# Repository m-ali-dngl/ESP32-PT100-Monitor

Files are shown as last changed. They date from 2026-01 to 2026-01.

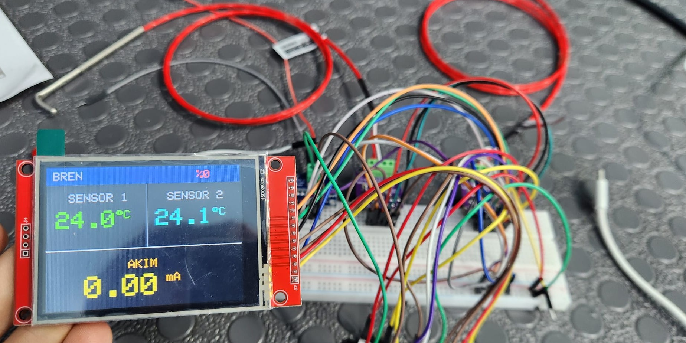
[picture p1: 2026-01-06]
Docs/Görsel.jpeg

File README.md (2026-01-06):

#  ESP32 Industrial Dual-Channel PT100 & Power Monitor

##  Overview

This project is designed for field engineers and technicians who need to monitor temperature and power parameters simultaneously. It utilizes the **ESP32** microcontroller to process data from two **PT100 RTD sensors** (via MAX31865) and an **INA219** current sensor. The data is displayed on a crisp **2.8" ILI9341 TFT screen** with a custom graphical user interface.

##  Key Features

* **Dual Temperature Monitoring:** High-precision reading from 2x PT100 sensors using MAX31865 (SPI).
* **Power Analysis:** Real-time current monitoring (mA) for external loads via INA219 (I2C).
* **Battery Management:**
    * Integrated 3.7V Li-Po battery support.
    * On-board charging (TP4056) and Boost Converter (MT3608) for stable 5V system power.
    * **Smart Battery Level:** ADC-based voltage monitoring with a voltage divider (100kΩ/100kΩ) and software calibration.
* **User Interface:**
    * Custom boot logo (Splash Screen).
    * Color-coded alerts (Green/Yellow/Red) for battery levels and sensor status.
* **PCB Design:** Schematic and PCB layout created in **Altium Designer**.

##  Project Structure

```text
├── Software/          # Arduino source codes (.ino) and header files
├── Hardware/          # Altium Designer Project files
└── Docs/              # Documentation, schematics PDF, and images

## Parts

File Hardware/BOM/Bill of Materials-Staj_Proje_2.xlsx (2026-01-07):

Comment | Description | Designator | Footprint | LibRef | Quantity
RES_100K | RES_100K | R1, R2 | RES | RES_100K | 2
SCREEN | SCREEN | SCR1 | LCD | SCREEN | 1
SWİTCH | SWİTCH | SW1 | SWİTCH | SWİTCH | 1
MAX 31865 | MAX 31865 | U1, U4 | MAX31865 | MAX_31865 | 2
TP4056 | TP4056 | U2 | TP4056 | TP4056 | 1
MT3608 | MT3608 | U3 | MT3608 | MT3608 | 1
INA219 | INA219 | U5 | INA219 | INA_219 | 1
ESP32 | ESP32 | U6 | ESP32 | ESP32 | 1

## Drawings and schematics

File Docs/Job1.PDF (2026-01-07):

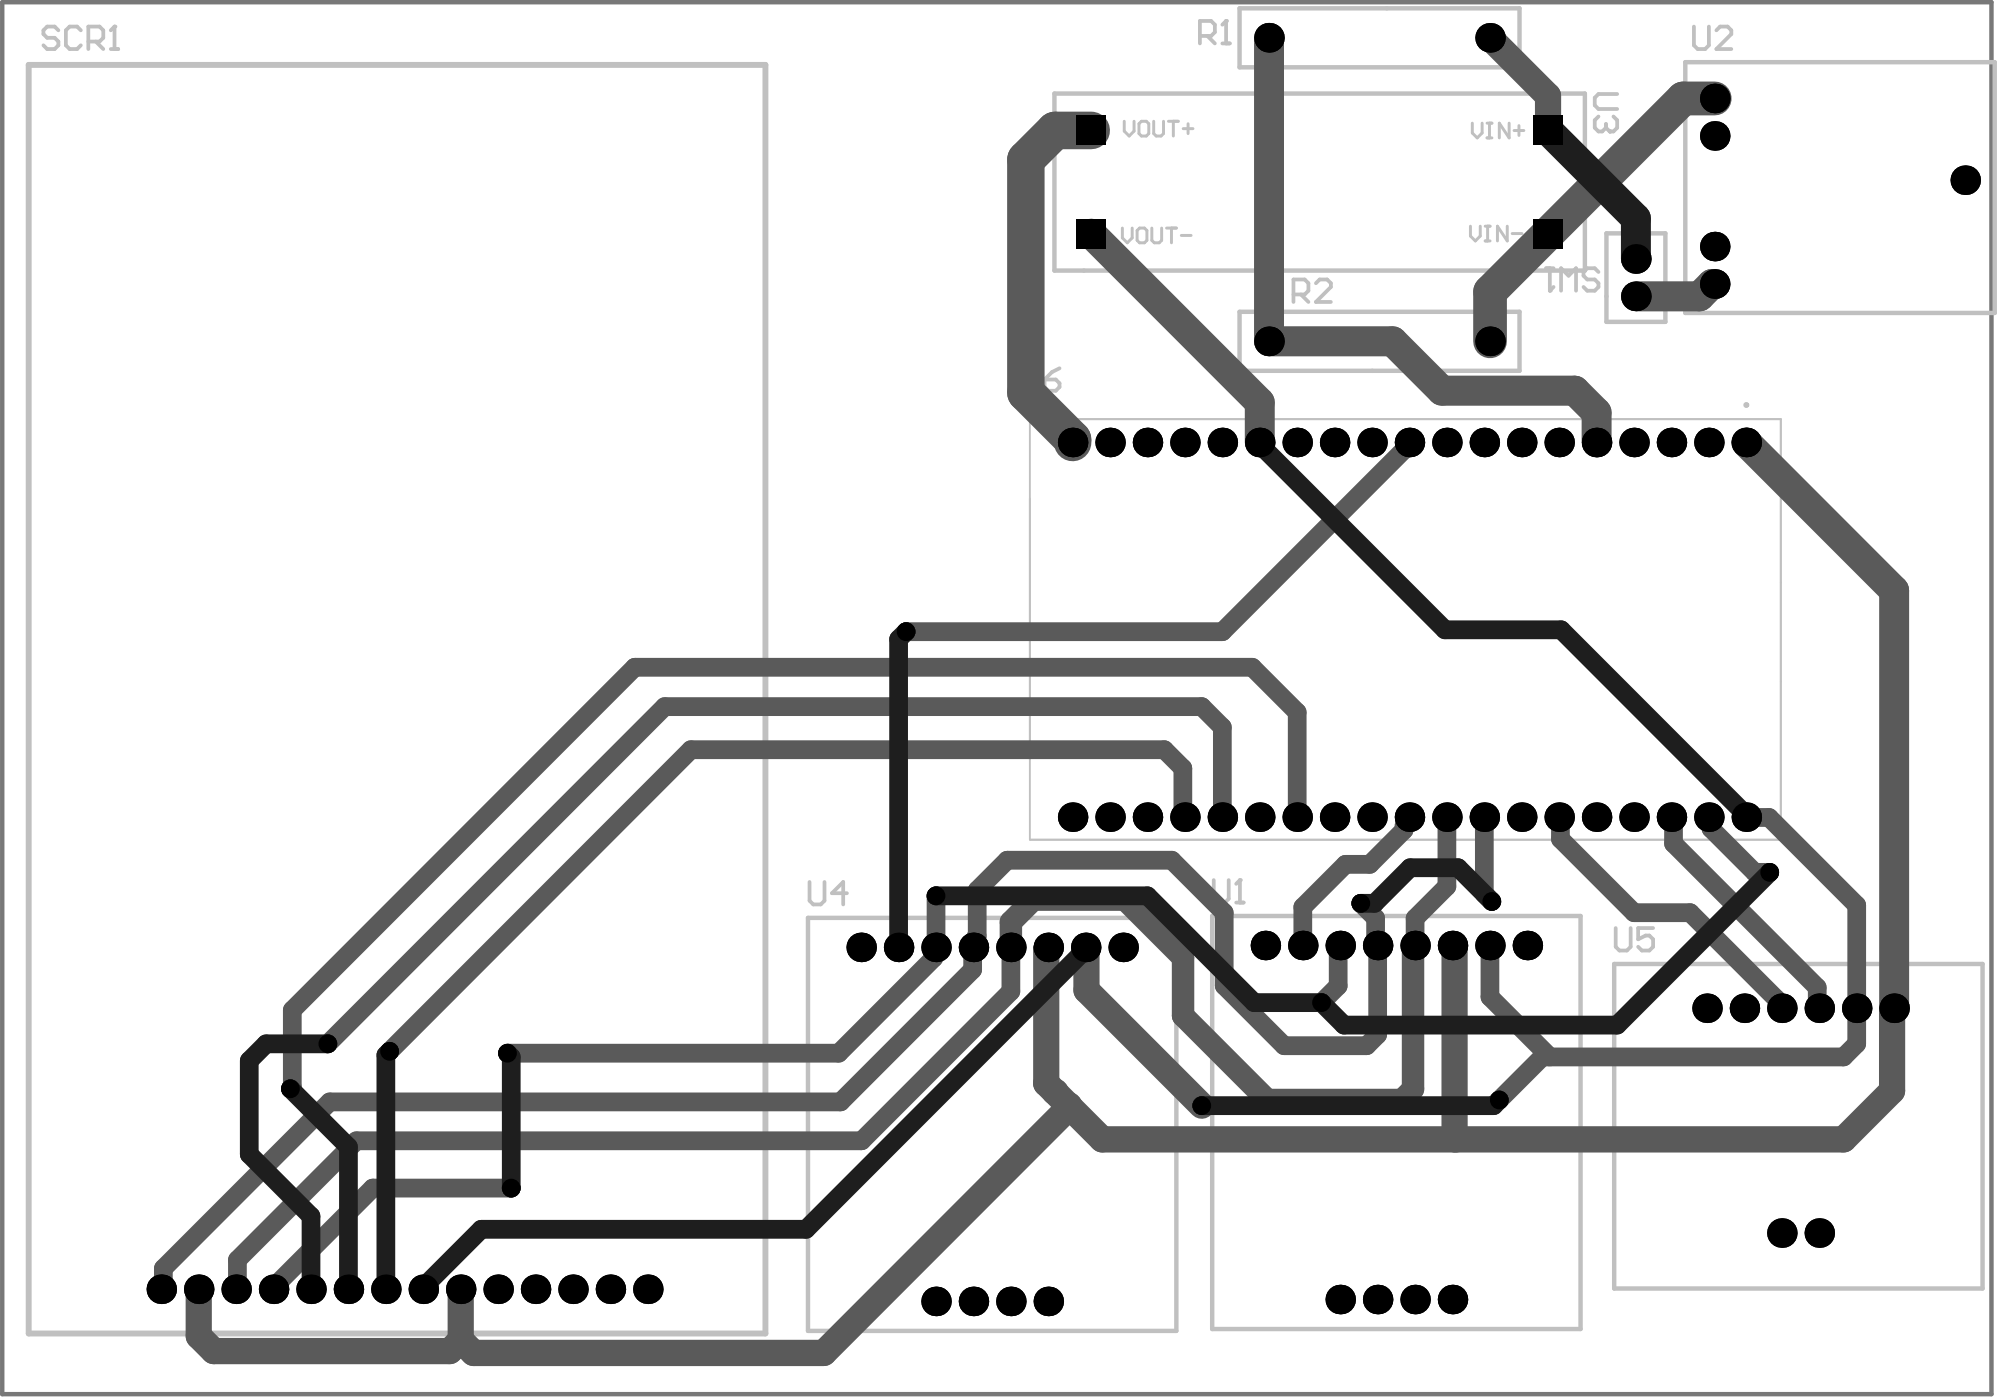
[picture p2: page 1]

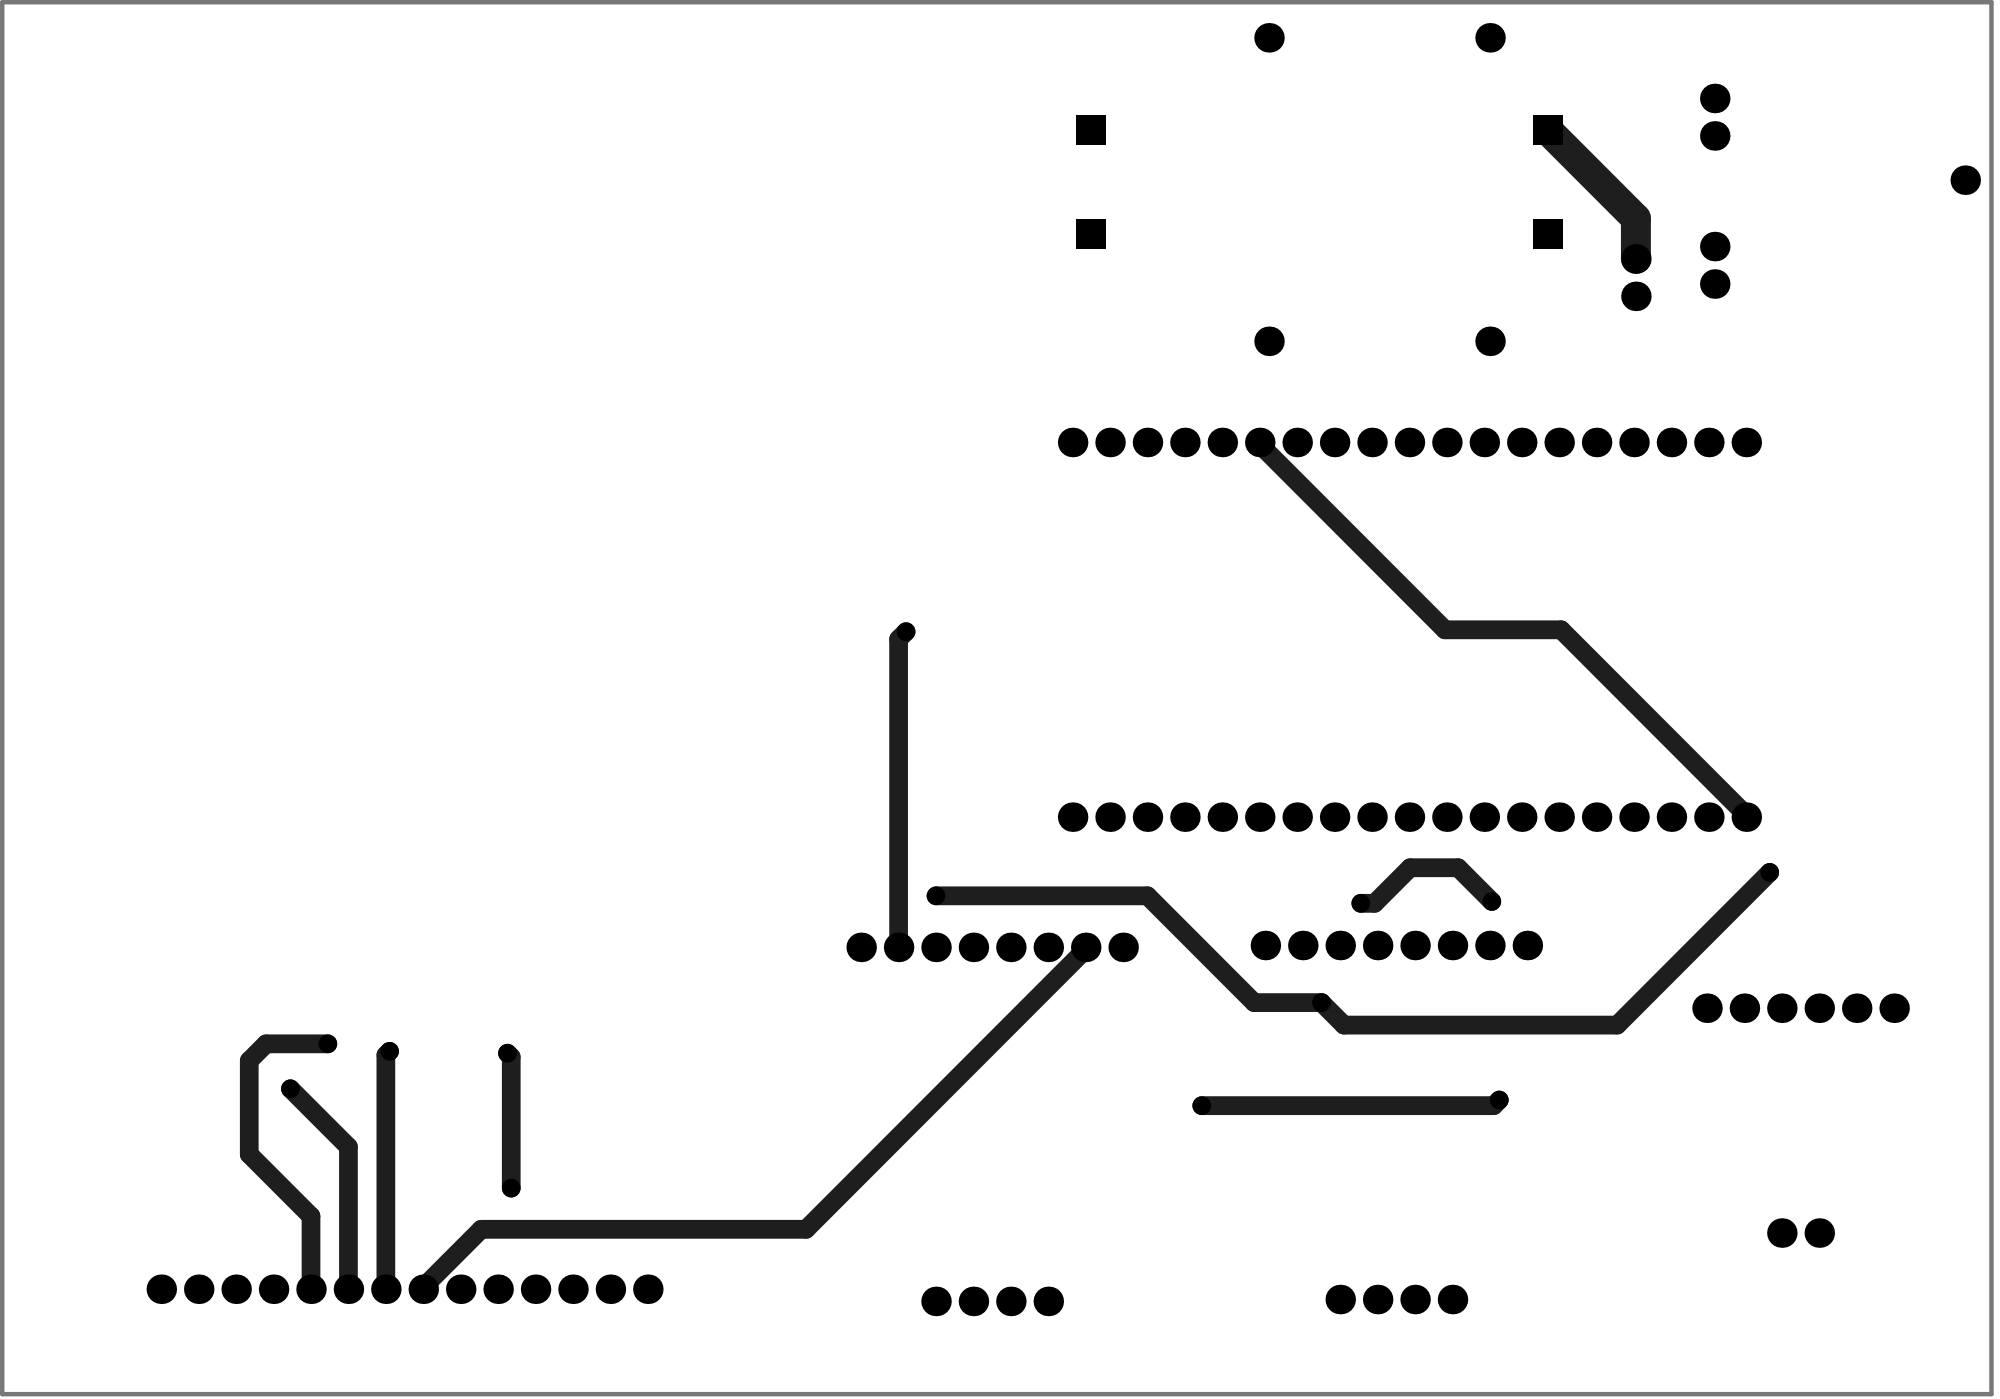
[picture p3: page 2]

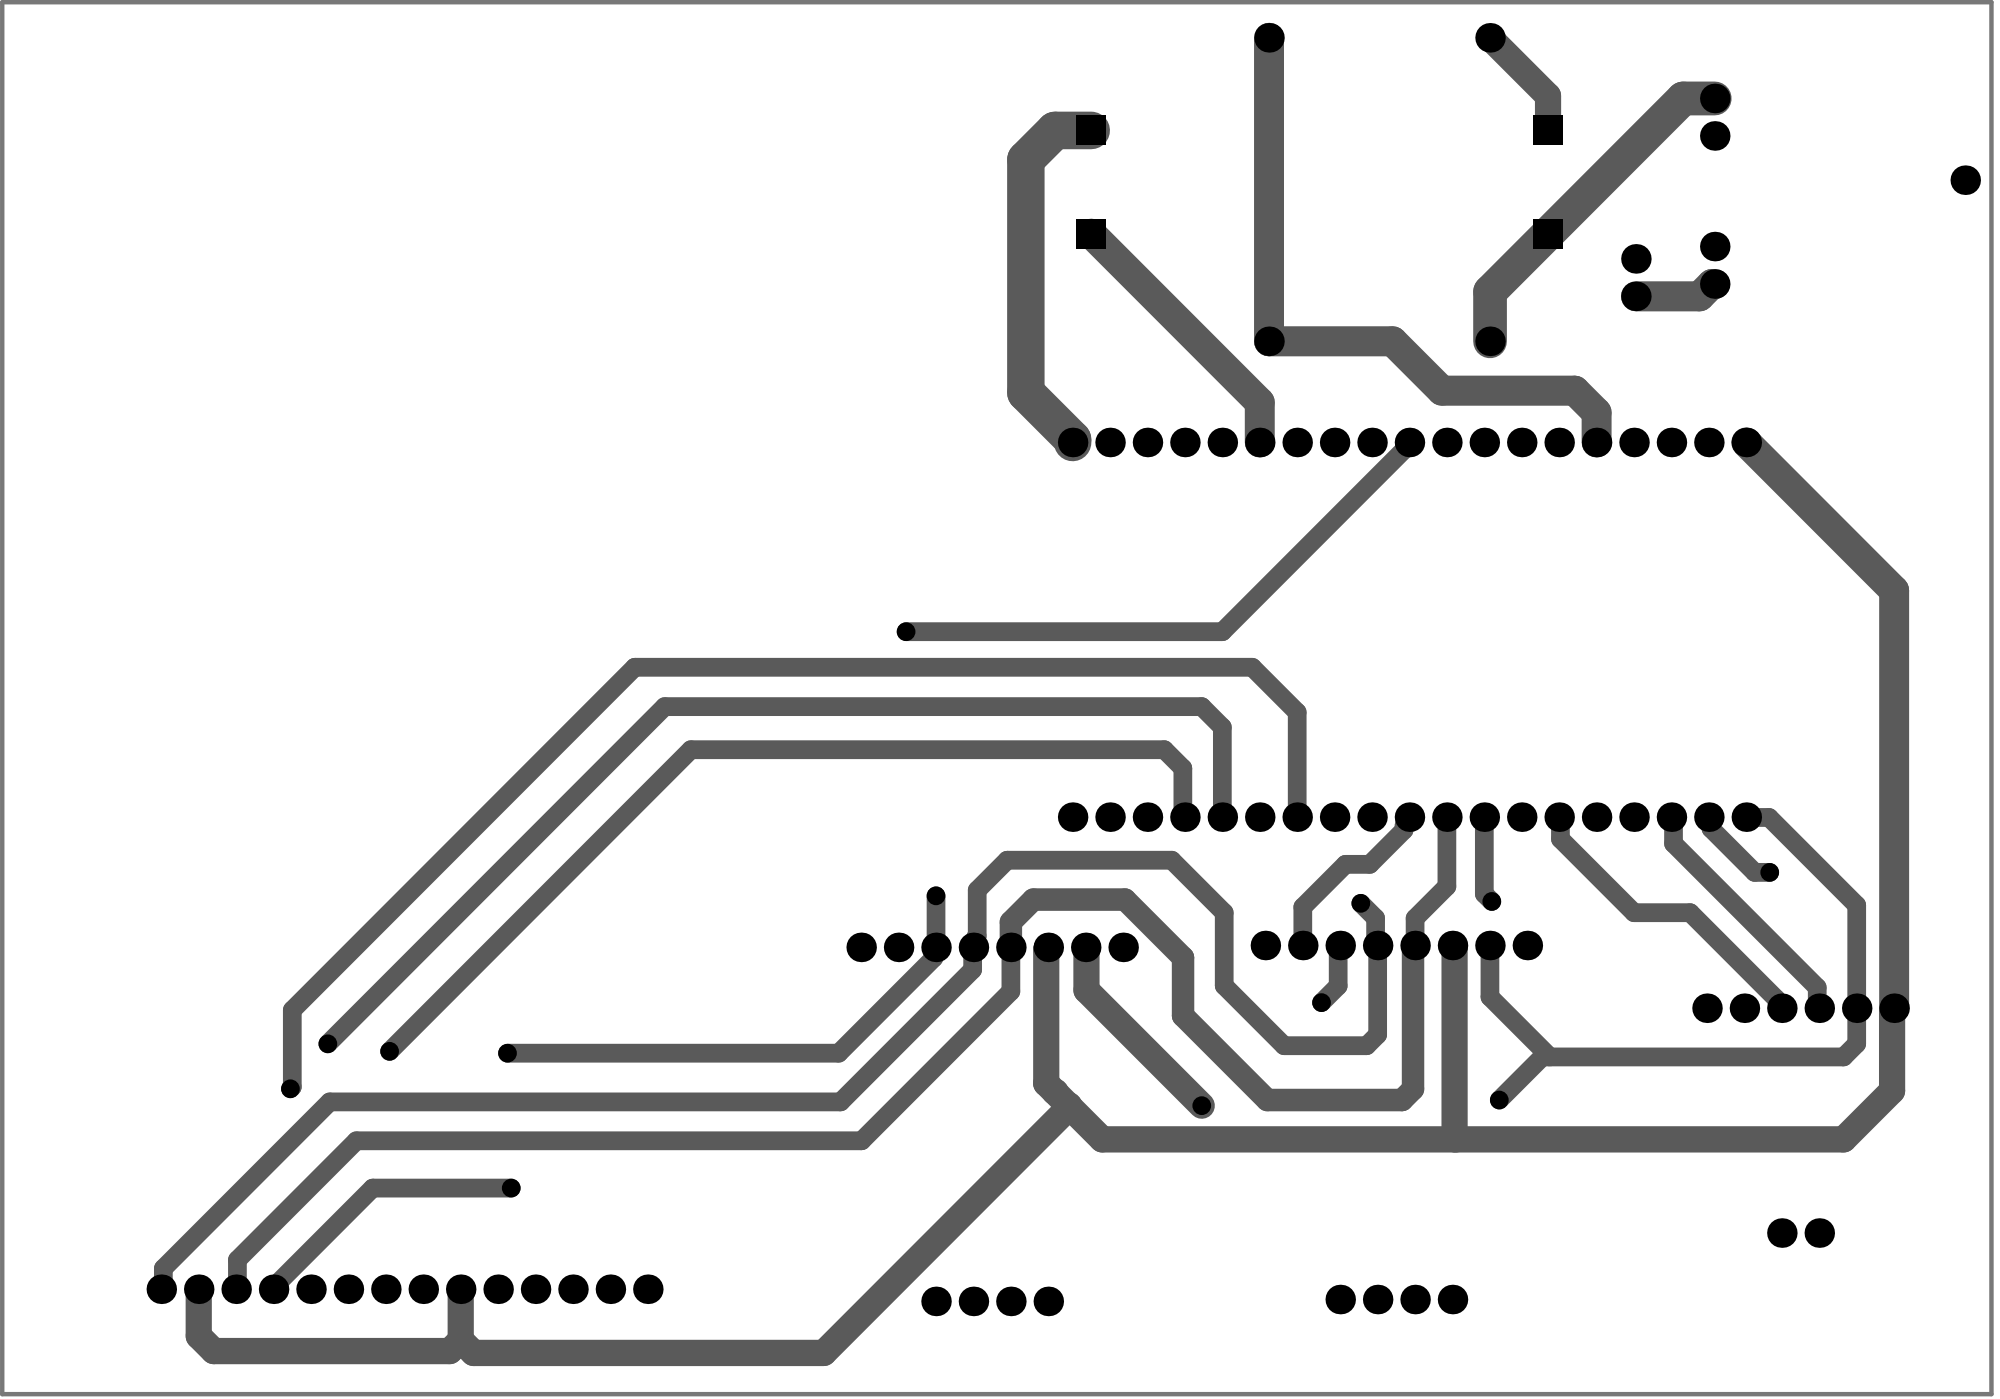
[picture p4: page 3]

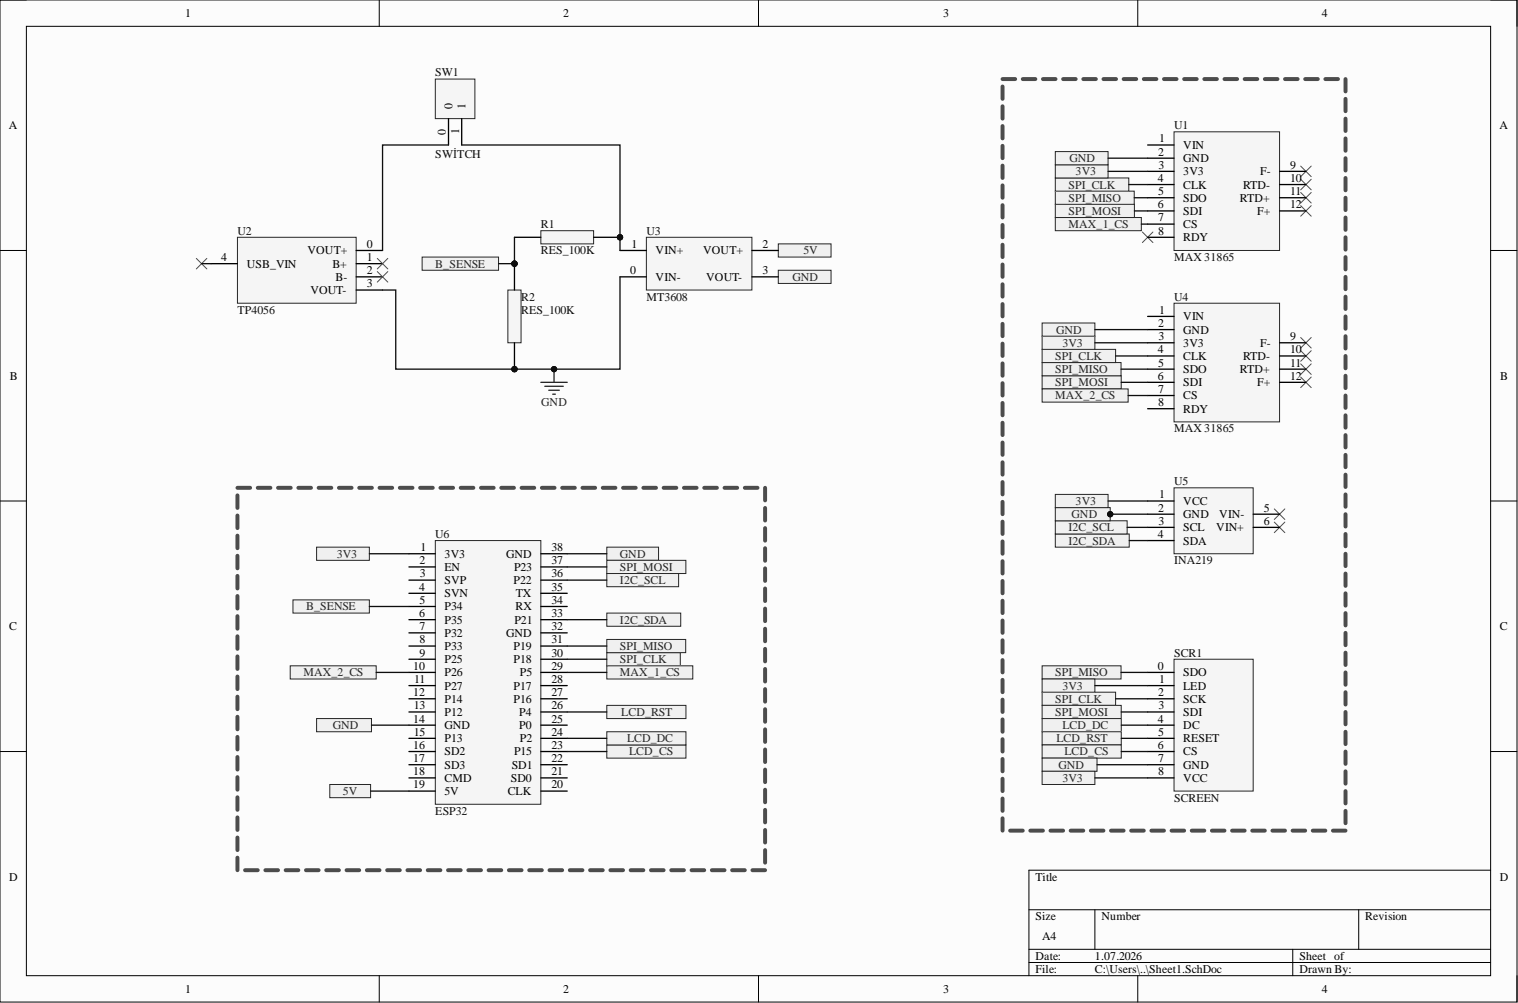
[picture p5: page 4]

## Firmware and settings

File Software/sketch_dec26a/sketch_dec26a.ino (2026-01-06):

#include <SPI.h>
#include <Wire.h>
#include <Adafruit_GFX.h>
#include <Adafruit_ILI9341.h>
#include <Adafruit_MAX31865.h>
#include <Adafruit_INA219.h>
#include "logo.h" 

// --- PIN TANIMLARI ---
#define TFT_CS    15
#define TFT_DC    2
#define TFT_RST   4
#define MAX1_CS   5
#define MAX2_CS   26
#define BATARYA_PIN 34 

// --- AYARLAR ---
#define BATARYA_MAX_V 4.20
#define BATARYA_MIN_V 3.20
#define VOLTAJ_CARPANI  0.00170 // Kalibrasyonunu unutma
#define AKIM_DUZELTME 1.02
#define LOGO_GENISLIK 320
#define LOGO_YUKSEKLIK 240
#define RREF      430.0
#define RNOMINAL  100.0

// --- NESNELER ---
Adafruit_ILI9341 tft = Adafruit_ILI9341(TFT_CS, TFT_DC, TFT_RST);
Adafruit_MAX31865 sensor1 = Adafruit_MAX31865(MAX1_CS);
Adafruit_MAX31865 sensor2 = Adafruit_MAX31865(MAX2_CS);
Adafruit_INA219 ina219;

void setup() {
  Serial.begin(115200);
  pinMode(BATARYA_PIN, INPUT); 

  sensor1.begin(MAX31865_3WIRE);
  sensor2.begin(MAX31865_3WIRE);
  if (!ina219.begin()) { Serial.println("INA219 Hatasi!"); }

  tft.begin();
  tft.setRotation(1);

  // Açılış Logosu
  tft.drawRGBBitmap(0, 0, logo_resmi, LOGO_GENISLIK, LOGO_YUKSEKLIK);
  delay(3000); 

  arayuzuCiz(); 
}

void loop() {
  // --- VERİ OKUMA ---
  float temp1 = sensor1.temperature(RNOMINAL, RREF);
  float temp2 = sensor2.temperature(RNOMINAL, RREF);
  sensor1.clearFault(); sensor2.clearFault();

  float current_mA = ina219.getCurrent_mA() * AKIM_DUZELTME;

  // Batarya Okuma
  long toplamADC = 0;
  for(int i=0; i<20; i++){ toplamADC += analogRead(BATARYA_PIN); delay(2); }
  float bataryaVoltaji = (toplamADC / 20.0) * VOLTAJ_CARPANI; 
  int pilYuzdesi = map(bataryaVoltaji * 100, BATARYA_MIN_V * 100, BATARYA_MAX_V * 100, 0, 100);
  pilYuzdesi = constrain(pilYuzdesi, 0, 100);

  // --- EKRAN GÜNCELLEME ---

  // 1. Batarya Yüzdesi (Sağ Üst)
  tft.fillRect(240, 5, 70, 20, ILI9341_NAVY); 
  tft.setCursor(245, 7); tft.setTextSize(2);
  if (pilYuzdesi < 20) tft.setTextColor(ILI9341_RED);
  else if (pilYuzdesi < 50) tft.setTextColor(ILI9341_YELLOW);
  else tft.setTextColor(ILI9341_GREEN);
  tft.print("%"); tft.print(pilYuzdesi);

  // 2. Sensör 1 
  tft.fillRect(10, 75, 140, 40, ILI9341_BLACK); 
  tft.setCursor(15, 75); tft.setTextSize(4); 
  if(temp1 < -100 || temp1 > 800) { tft.setTextColor(ILI9341_RED); tft.print("HATA"); } 
  else { tft.setTextColor(ILI9341_GREEN); tft.print(temp1, 1); tft.setTextSize(2); tft.print((char)247); tft.print("C"); }

  // 3. Sensör 2 
  tft.fillRect(170, 75, 140, 40, ILI9341_BLACK);
  tft.setCursor(175, 75); tft.setTextSize(4);
  if(temp2 < -100 || temp2 > 800) { tft.setTextColor(ILI9341_RED); tft.print("HATA"); } 
  else { tft.setTextColor(ILI9341_CYAN); tft.print(temp2, 1); tft.setTextSize(2); tft.print((char)247); tft.print("C"); }

  // 4. Akım Değeri 
  tft.fillRect(50, 185, 260, 45, ILI9341_BLACK); 
  tft.setCursor(60, 185); tft.setTextSize(5); tft.setTextColor(ILI9341_YELLOW);
  tft.print(current_mA, 2); 
  tft.setTextSize(2); tft.setTextColor(ILI9341_ORANGE); tft.print(" mA");         

  delay(1000);
}

// --- ARAYÜZ TASARIMI ---
void arayuzuCiz() {
  tft.fillScreen(ILI9341_BLACK);
  
  // Üst Bant
  tft.fillRect(0, 0, 320, 30, ILI9341_NAVY);
  tft.setCursor(10, 7); tft.setTextColor(ILI9341_WHITE); tft.setTextSize(2);
  tft.print("BREN");

  // Çizgiler 
  tft.drawLine(160, 30, 160, 140, ILI9341_DARKGREY); 
  tft.drawLine(0, 140, 320, 140, ILI9341_WHITE);     

  // Başlıklar
  tft.setTextSize(2); tft.setTextColor(ILI9341_LIGHTGREY);

  tft.setCursor(35, 45); tft.print("SENSOR 1");
  tft.setCursor(195, 45); tft.print("SENSOR 2");

  // Akım Başlığı 
  tft.setTextColor(ILI9341_ORANGE);
  tft.setCursor(130, 160); tft.print("AKIM"); 
}

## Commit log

2026-01-06 Initial release: Firmware source code and Altium PCB design
    Uploaded the first version of the ESP32 Industrial Monitor project.
    Key inclusions:
    - Arduino Firmware: Support for PT100 (MAX31865), INA219, and ILI9341 display.
    - Hardware Design: Altium Designer project files (Schematic & PCB Layout).
    - Documentation: Project README, pinout table, and schematic export.
    [Bill of Materials-Staj_Proje_2.xlsx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]
2026-01-07 Error fixed
    [Bill of Materials-Staj_Proje_2.xlsx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]
